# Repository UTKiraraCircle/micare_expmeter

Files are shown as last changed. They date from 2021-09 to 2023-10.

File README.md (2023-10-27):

# micare_expmeter
micare vol.1 に寄稿した記事「もゆもゆに露出計を捧ぐ」で製作した露出計の使用素材・掲載ソースコードの注釈など

## 今回の製作にあたって使用したハード・ソフトのマテリアル
### 素子
* Raspberry Pi Pico
* [Seeed Studio Raspberry Pi Pico用 OLEDディスプレイモジュール【103030401】](https://www.marutsu.co.jp/pc/i/2223782/)
  * ドライバICは SH1107
  * ほかにcircuitpythonのライブラリが確認できた電子ペーパー・LCD/OLEDディスプレイのドライバICは以下の通り
    * IL0398
    * SH1106
    * SH1107
    * SSD1305
    * SSD1306
    * SSD1325
    * SSD1327
* Adafruit TSL2591 光センサモジュール
* 【warning】今回は複数のI2Cスレーブデバイスを同じI2Cバスに繋ぐことができなかったため、光センサをI2C通信、OLEDをSPI通信で駆動した
### 配線部品・電源
* ピンヘッダ
  * 両端ロングが望ましい
* メス―メスジャンパワイヤ
* 熱収縮チューブφ1.5
  * φ2が望ましいと思われる
* はんだ線
* 単4乾電池*2
* 同電池ボックス
* 1回路1接点トグルスイッチ
* ほかに試作段階で ブレッドボード オス―オスジャンパワイヤ を使用
### 開発言語
* circuitpython 6.3.0
### 開発環境
* Thonny ver 1.1.16, 1.1.17

## 掲載ソースコードの注釈
* README.md このファイル
* blink_LED.py オンボードLEDを用いたLチカ マイコンの動作確認用
* ExpMeter_Sensor.py 感度の自動設定のためのコード 試作段階で生えたもの
* **code_final_with_comments.py 2021 9/27 時点で最新のコード コメントつき**
* **code_final_WITHOUT_comments.py 2021 9/27 時点で最新のコード コメントなし**

## 改善点と今後の展望
* 折角ディスプレイにボタンがあるので, 感度設定させたりモード切替ができるといい
* 外装面でも大きなフード, ディフューザーを付けたり金属ケースに入れるべき 実際迷光に惑わされてセンサが停止することが多かった
* 金属のホットシュー足をジャンクストロボからぶんどって取り付けるべき
* 電源はボタン電池・買い置きしてるCR2032を2つ使って小型軽量化する
* RP2040を使ったオリジナルボードを作ってもいい

## stlファイルの注釈
* 露出計本体.stl シューの形状はPENTAX SPのアクセサリシューに合わせた PENTAX KPには嵌ったが、PENTAX KMのシューに嵌めるにはやすりによる加工が必要だった。予め取り付け先の形状を測定することを勧める
* 廂.stl 光センサ部分の側面からの光の入射を防ぐ廂 ネジは2mm径のものがよい
* 側面蓋.stl 露出計を入れた後、側面に蓋をする部品 もう少し固定部分に遊びがあっても良かったかもしれない

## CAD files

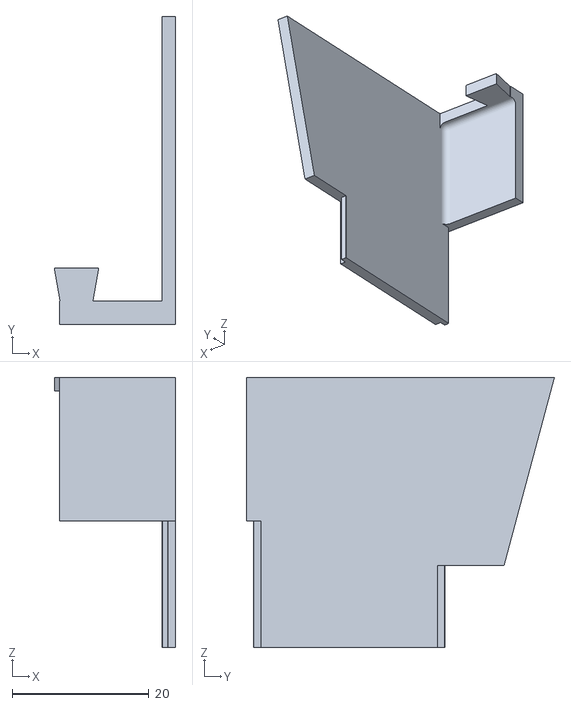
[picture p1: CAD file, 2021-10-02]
側面蓋.stl
17.8 x 45.0 x 39.5

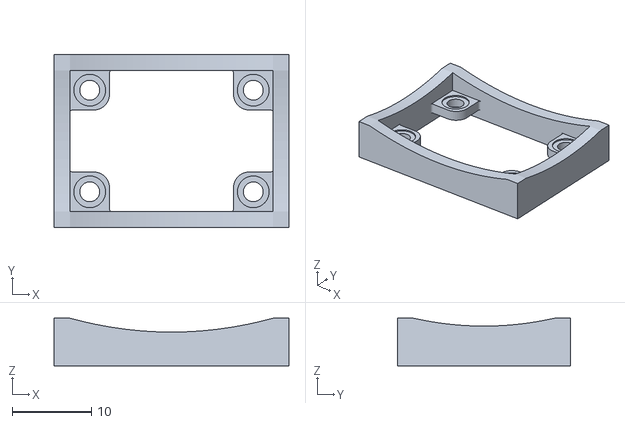
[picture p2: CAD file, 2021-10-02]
廂.stl
29.6 x 21.8 x 6.00

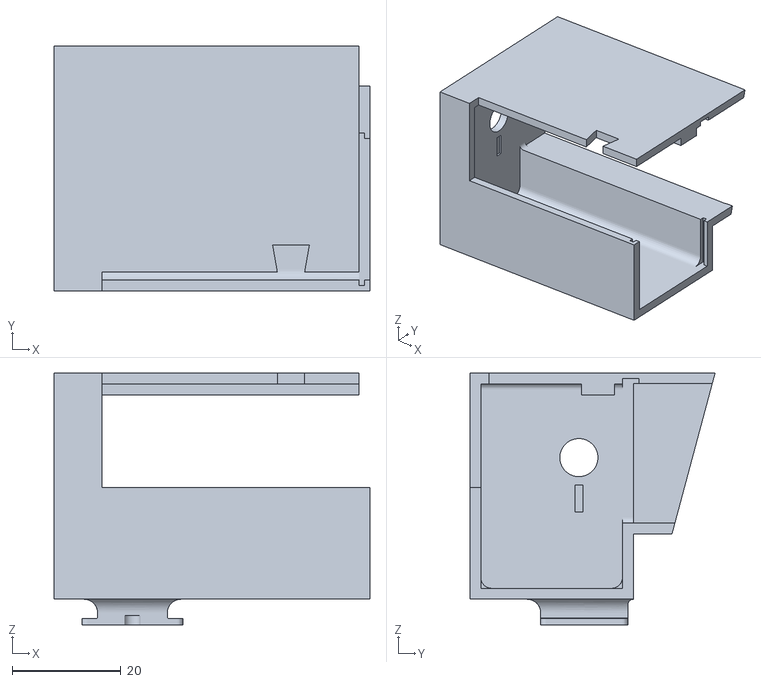
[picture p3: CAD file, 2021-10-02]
露出計本体.stl
58.0 x 45.0 x 46.2

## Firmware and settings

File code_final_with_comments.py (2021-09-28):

"""
個人使用 引用を付しての参照・言及可
For personal use, citation with reference approved.
商業的な二次配布禁止
Commercial secondary destribution prohibited.
実際にPicoに保存して動かす場合はファイル名を "code.py" とすること
You must rename this file as "code.py" when you use this file as a driver of your Pico. 
"""

# 必要なライブラリをインポート
import math, time, adafruit_tsl2591, terminalio, displayio
from board import *
from busio import I2C, SPI
from adafruit_displayio_sh1107 import SH1107
from adafruit_display_text import label

# 光センサ、ディスプレイを駆動するためのI2C、SPI通信を有効化 GP~はマイコンのピン指定
i2c = I2C(GP27,GP26)
sensor = adafruit_tsl2591.TSL2591(i2c, address = 0x29)
displayio.release_displays()
spi = SPI(clock = GP10, MOSI = GP11)
display_bus = displayio.FourWire(spi, command = GP8, chip_select = GP9, reset = GP12)
display = SH1107(display_bus ,width = 128,height = 64)

# ディスプレイに表示する文字列のうち内容が決まっているものを定義
gainlist = ['LOW ','MED ','HIGH','MAX ']
Tlist = ['1', '1/2', '1/4', '1/8', '1/15', '1/30', '1/60', '1/125', '1/250', '1/500', '1/1000', '1/2000', '1/4000']

# 電源が入っている間は以下の処理を無限に繰り返す
while True:
    # 最初は低感度に設定して強い光にも対応
    #初手でセンサ感度が高いとエラー処理が面倒なので低感度に設定
    sensor.gain = adafruit_tsl2591.GAIN_LOW
    k = 0
    while k < 4: # 測光してすぐの値は荒ぶるので4回目の測光値を感度調整に使用
        Ev = math.log(float(sensor.lux)/2.5, 2)
        # Pico用のcircuitpythonのmathモジュールにはどういうわけかlog2函数がないのでこれで代用
        if Ev < 1.5:
            #あまりに暗いと対数函数の真数0エラーを吐くのでwhileループ中でも早めに離脱させる
            sensor.gain = adafruit_tsl2591.GAIN_MED
            Ev = math.log(float(sensor.lux)/2.5, 2)
            break
        time.sleep(0.1)
        k += 1
    # 最初の値ごとに感度をあらためて設定
    if Ev < 2.3:
        sensor.gain = adafruit_tsl2591.GAIN_MAX
    elif Ev < 6.5:
        sensor.gain = adafruit_tsl2591.GAIN_HIGH
    elif Ev < 9:
        sensor.gain = adafruit_tsl2591.GAIN_MED
    else:
        sensor.gain = adafruit_tsl2591.GAIN_LOW
    # ここで使用するセンサ感度が決まるのでディスプレイの表示内容を決めておく
    gain = gainlist[int(sensor.gain/16)]
    
    # ディスプレイ表示に使う明るさを調整した感度で測光
    k = 0
    while k < 5:
        Ev = math.log(float(sensor.lux)/2.5,2)
        time.sleep(0.1)
        k += 1
    
    Ev1 = Ev + 2 # 実地試験の結果を鑑みて測光された露出を補正
    splash = displayio.Group() # splash...のあたりなんも理解していない JKすぷらっしゅ...?
    text_group = displayio.Group(scale = 1, x = 1, y = 3)
    # 1行目はユーザーが直接求める情報ではないので小さく表示
    text = "GAIN:" + gain + " Ev:" + str(Ev1) # 1行目の表示
    text_area = label.Label(terminalio.FONT, text=text, color=0xFFFF00)
    text_group.append(text_area)
    splash.append(text_group)
    
    #ISO400までの参考露出を計算して表示
    for N in range(3):
        Ev2 = Ev1 + N
        # フィードバックをもとに露出計算部分を改修
        if Ev2 < 4:
            Av = 2
            Tv = Ev2 - 2
            T = str(round(2**(-Tv),1)) #長いシャッタ―は秒数を直接表示
        else:
            # 明るい場合にシャッタースピードが小さく出るよう、Tvを切り上げ
            Tv = math.ceil(Ev2/2)
            T = Tlist[Tv]
            Av = Ev2 - Tv
        # 絞り値を計算
        Araw = 2**(Av/2)
        if Araw//10 == 0:
            A = math.floor(10*Araw)/10 # 10未満のF値は小数点以下第2位以降を切り捨て
        else:
            A = math.floor(Araw) # 10以上のF値は整数値で表示
        Exp =str(A) + " " + T # これが参考露出1行分 これを3回別のISO感度で繰り返す
        text_group=displayio.Group(scale = 2, x = 1, y = int(15 + 17 * N))
        text_area = label.Label(terminalio.FONT,text=Exp,color=0xFFFF00)
        text_group.append(text_area)
        splash.append(text_group)
    display.show(splash) #JKすぷらっしゅ

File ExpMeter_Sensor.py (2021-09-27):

import math, time, adafruit_tsl2591
from board import *
from busio import I2C

i2c = I2C(GP27,GP26)
TSL_addr = 0x29
sensor = adafruit_tsl2591.TSL2591(i2c, address = TSL_addr)
sensor.gain = adafruit_tsl2591.GAIN_LOW
k = 0
while k<4:
    Ev = math.log(float(sensor.lux)/2.5,2)
    time.sleep(0.1)
    k += 1
if Ev < 2:
    sensor.gain = adafruit_tsl2591.GAIN_MAX
elif Ev < 6.7:
    sensor.gain = adafruit_tsl2591.GAIN_HIGH
elif Ev <10:
    sensor.gain = adafruit_tsl2591.GAIN_MED
gainlist = ['LW','MD','HI','MX']
k = 0
while k<4:
    Ev = math.log(float(sensor.lux)/2.5,2)
    time.sleep(0.1)
    k += 1
print(Ev)
print(gainlist[int(sensor.gain/16)])

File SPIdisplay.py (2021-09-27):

from board import *
import busio, terminalio, displayio, time
from adafruit_displayio_sh1107 import SH1107
from adafruit_display_text import label

displayio.release_displays()
spi = busio.SPI(clock=GP10 ,MOSI=GP11)
display_bus = displayio.FourWire(spi, command=GP8, chip_select=GP9, reset=GP12)
display = SH1107(display_bus, width = 128, height =64)

splash = displayio.Group()
display.show(splash)

text_group = displayio.Group(scale = 2, x = 0, y = 6)
#text group、表示させるもの?

text = "GAIN:"
text_area = label.Label(terminalio.FONT, text=text, color=0xFFFF00)
text_group.append(text_area)  # Subgroup for text
splash.append(text_group)

text2 = "HIGH"
text_group = displayio.Group(scale = 2, x = 60, y = 6)
text_area2 = label.Label(terminalio.FONT, text=text2, color=0xFFFF00)
text_group.append(text_area2)  # Subgroup for text
splash.append(text_group)
